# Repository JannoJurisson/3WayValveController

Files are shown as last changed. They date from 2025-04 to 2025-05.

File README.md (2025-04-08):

# 3WayValveController
Atmega328 based 3-way valve controller using a MG995 servo motor

A standalone controller using a Dallas DS18B20 sensor as input and MG995 servo motor as output that moves 3-way valve. Two end switches help to position the valve.

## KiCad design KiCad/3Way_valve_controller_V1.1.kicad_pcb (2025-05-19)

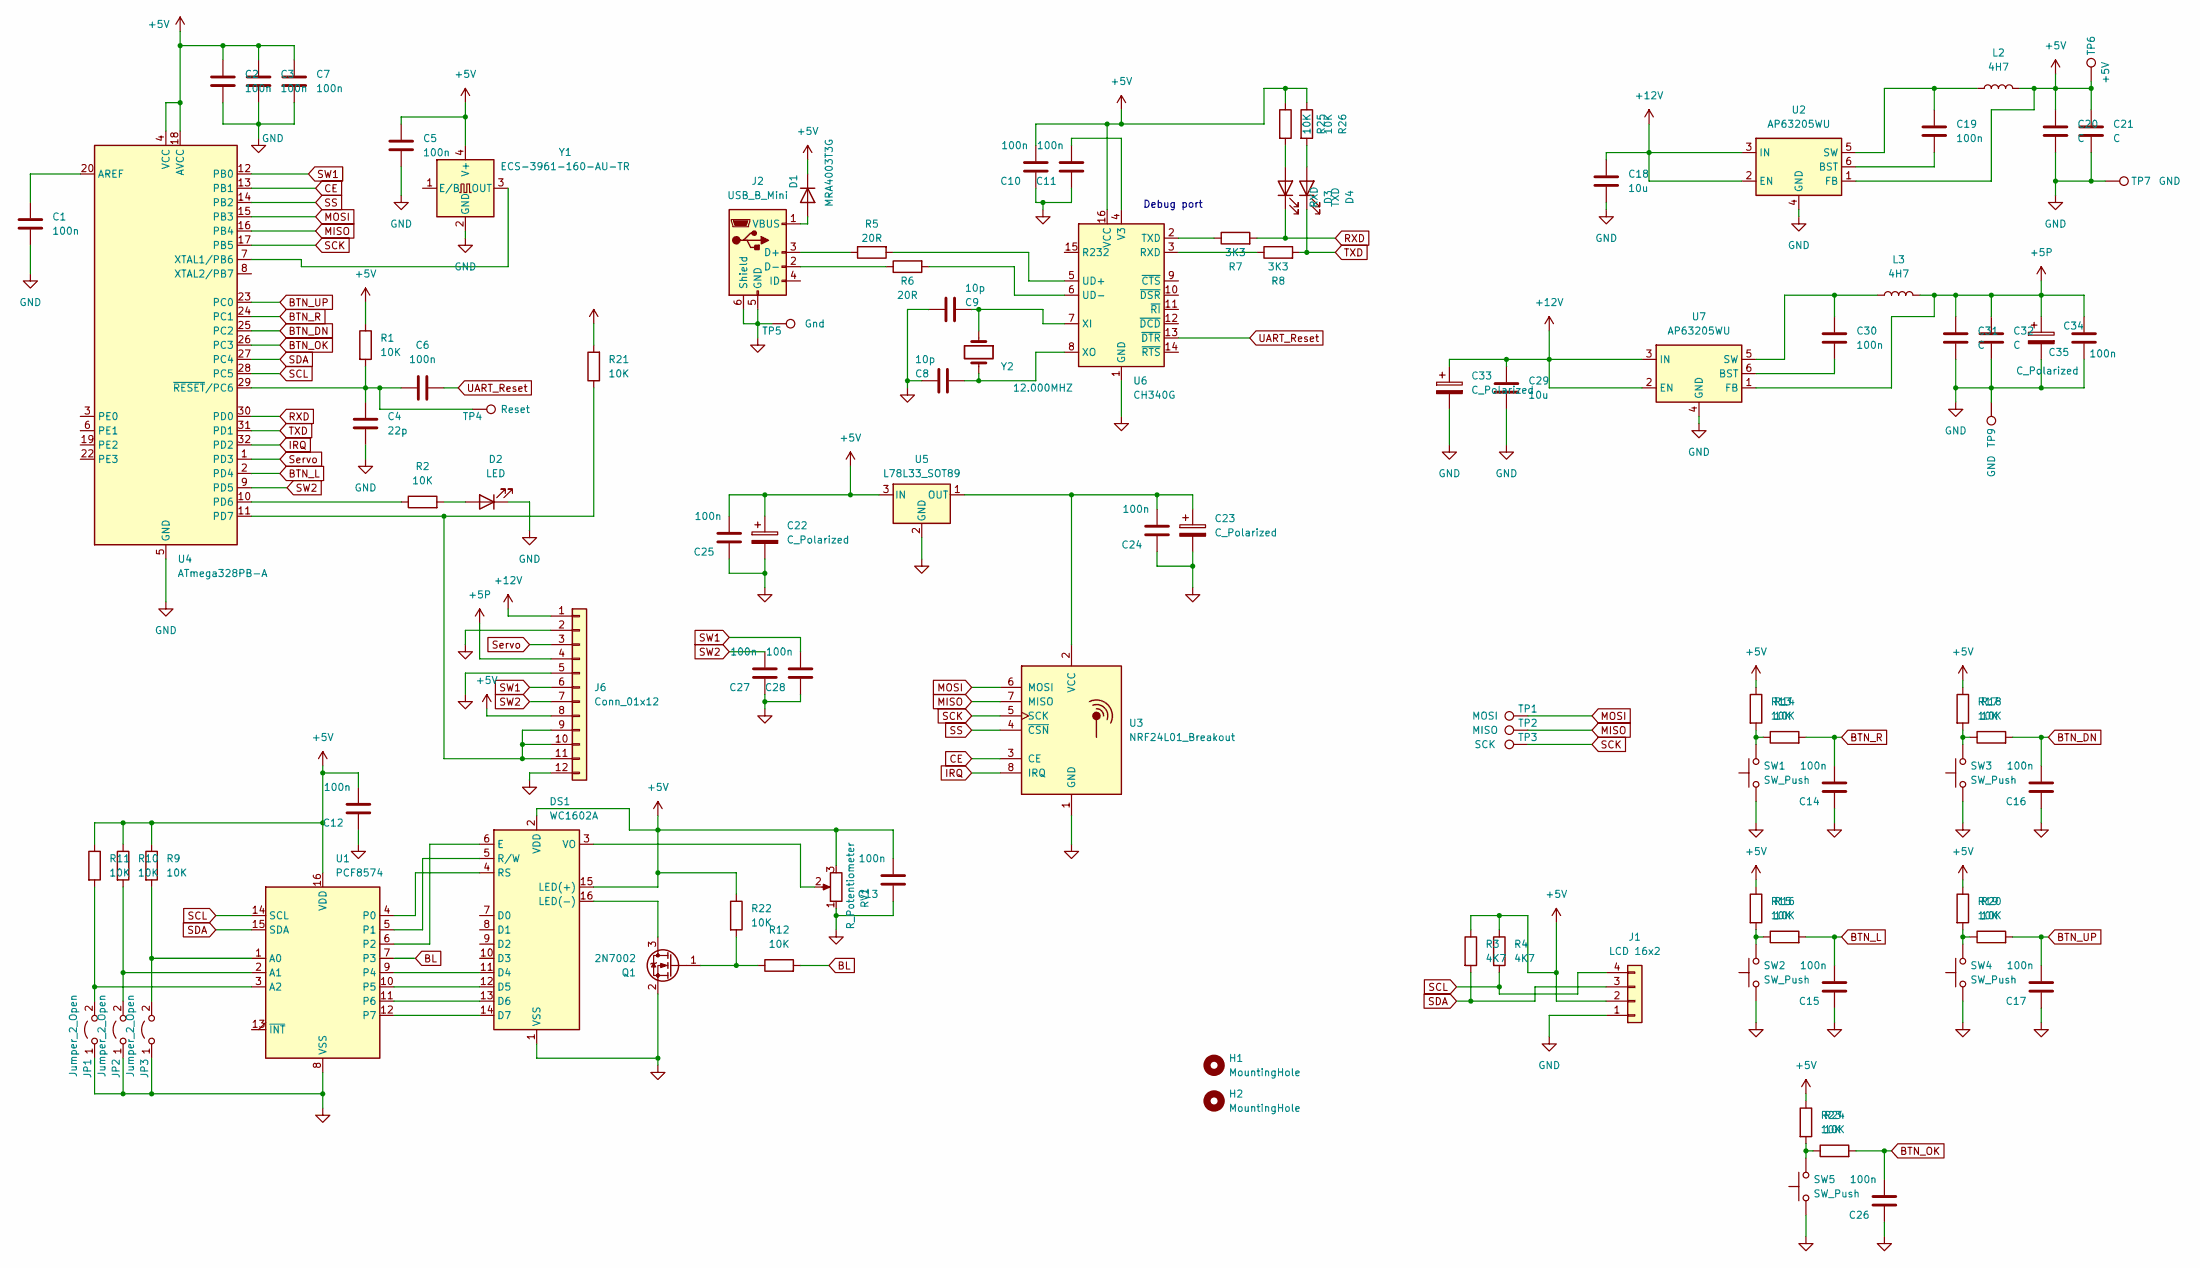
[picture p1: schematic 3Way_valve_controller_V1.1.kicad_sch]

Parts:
C1, C2, C3, C5, C6, C7, C14, C15, C16, C17, C19, C26, C30: 100n; C_0603_1608Metric
C4: 22p; C_0603_1608Metric
C8, C9: 10p; C_0603_1608Metric_Pad1.08x0.95mm_HandSolder
C10, C11, C12, C13, C24, C25, C27, C28, C35: 100n; C_0603_1608Metric_Pad1.08x0.95mm_HandSolder
C18, C29: 10u; C_1206_3216Metric
C20, C21, C31, C32: C; C_1206_3216Metric
C22, C23, C33, C34: C_Polarized; CP_Elec_10x10
D1: MRA4003T3G; D_SMA
D2: LED; LED_1206_3216Metric
D3: RXD; LED_1206_3216Metric
D4: TXD; LED_1206_3216Metric
DS1: WC1602A
H1, H2: MountingHole; MountingHole_3.2mm_M3
J1: LCD 16x2; PinHeader_1x04_P2.54mm_Vertical
J2: USB_B_Mini; JLCPCB_C404968_Micro_USB
J6: Conn_01x12; PhoenixContact_MCV_1,5_12-GF-3.5_1x12_P3.50mm_Vertical_Thre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
JP1, JP2, JP3: Jumper_2_Open; SolderJumper-2_P1.3mm_Open_Pad1.0x1.5mm
L2, L3: 4H7; L_Bourns_SRP7028A_7.3x6.6mm
Q1: 2N7002; SOT-23
R1, R2, R9, R10, R11, R12, R13, R14, R15, R16, R17, R18, R19, R20, R21, R22, R23, R24, R25, R26: 10K; R_0603_1608Metric
R3, R4: 4K7; R_0603_1608Metric
R5, R6: 20R; R_0603_1608Metric_Pad0.98x0.95mm_HandSolder
R7, R8: 3K3; R_0603_1608Metric_Pad0.98x0.95mm_HandSolder
RV1: R_Potentiometer; Potentiometer_Vishay_T73YP_Vertical
SW1, SW2, SW3, SW4, SW5: SW_Push; SW_PUSH_6mm
TP1: MOSI; TestPoint_Pad_D1.5mm
TP2: MISO; TestPoint_Pad_D1.5mm
TP3: SCK; TestPoint_Pad_D1.5mm
TP4: Reset; TestPoint_Pad_D1.5mm
TP5: Gnd; TestPoint_Pad_D1.5mm
TP6: +5V; TestPoint_Pad_D1.5mm
TP7, TP9: GND; TestPoint_Pad_D1.5mm
U1: PCF8574; SOIC-16W_7.5x10.3mm_P1.27mm
U2, U7: AP63205WU; TSOT-23-6
U3: NRF24L01_Breakout; nRF24L01_Breakout
U4: ATmega328PB-A; TQFP-32_7x7mm_P0.8mm
U5: L78L33_SOT89; SOT-89-3
U6: CH340G; SOIC-16_3.9x9.9mm_P1.27mm
Y1: ECS-3961-160-AU-TR; Oscillator_SMD_EuroQuartz_XO53-4Pin_5.0x3.2mm
Y2: 12.000MHZ; Crystal_SMD_5032-2Pin_5.0x3.2mm

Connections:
+5P: C31.1, C32.1, C34.1, C35.2, J6.4, L3.2, U7.1 (FB)
+5V: C2.2, C3.2, C5.2, C7.2, C10.2, C12.2, C13.2, C20.1, C21.1, C22.1, C25.2, D1.1 (K), DS1.2 (VDD), DS1.15 (LED(+)), J1.2, J6.8, L2.2, R1.1, R3.1, R4.1, R9.1, R10.1, R11.1, R13.1, R15.1, R17.1, R19.1, R21.2, R22.1, R23.1, R25.1, R26.1, RV1.3, TP6.1, U1.16 (VDD), U2.1 (FB), U4.4 (VCC), U4.18 (AVCC), U5.3 (IN), U6.16 (VCC), Y1.4 (V+)
+12V: C18.1, C29.1, C33.1, J6.1, U2.2 (EN), U2.3 (IN), U7.2 (EN), U7.3 (IN)
BL: R12.2, U1.7 (P3)
BTN_DN: C16.2, R18.2, U4.25 (PC2)
BTN_L: C15.2, R16.2, U4.2 (PD4)
BTN_OK: C26.2, R24.2, U4.26 (PC3)
BTN_R: C14.2, R14.2, U4.24 (PC1)
BTN_UP: C17.2, R20.2, U4.23 (PC0)
CE: U3.3 (CE), U4.13 (PB1)
GND: C1.1, C2.1, C3.1, C4.1, C5.1, C7.1, C8.2, C9.2, C10.1, C11.1, C12.1, C13.1, C14.1, C15.1, C16.1, C17.1, C18.2, C20.2, C21.2, C22.2, C23.2, C24.1, C25.1, C26.1, C27.1, C28.1, C29.2, C31.2, C32.2, C33.2, C34.2, C35.1, D2.1 (K), DS1.1 (VSS), J1.1, J2.5 (GND), J2.6 (Shield), J6.2, J6.5, J6.12, JP1.1 (A), JP2.1 (A), JP3.1 (A), Q1.2 (S), RV1.1, SW1.1, SW2.1, SW3.1, SW4.1, SW5.1, TP5.1, TP7.1, TP9.1, U1.8 (VSS), U2.4 (GND), U3.1 (GND), U4.5 (GND), U4.21 (GND), U5.2 (GND), U6.1 (GND), U7.4 (GND), Y1.2 (GND)
IRQ: U3.8 (IRQ), U4.32 (PD2)
MISO: TP2.1, U3.7 (MISO), U4.16 (PB4)
MOSI: TP1.1, U3.6 (MOSI), U4.15 (PB3)
unnamed: D1.2 (A), J2.1 (VBUS)
unnamed: D2.2 (A), R2.2
unnamed: D3.2 (A), R25.2
unnamed: D4.2 (A), R26.2
unnamed: DS1.11 (D4), U1.9 (P4)
unnamed: DS1.12 (D5), U1.10 (P5)
unnamed: DS1.13 (D6), U1.11 (P6)
unnamed: DS1.14 (D7), U1.12 (P7)
unnamed: DS1.6 (E), U1.6 (P2)
unnamed: DS1.16 (LED(-)), Q1.3 (D)
unnamed: DS1.4 (RS), U1.4 (P0)
unnamed: DS1.5 (R/W), U1.5 (P1)
unnamed: DS1.3 (VO), RV1.2
unnamed: J2.3 (D+), R5.1
unnamed: J2.2 (D-), R6.1
unnamed: J6.9, J6.10, J6.11, R21.1, U4.11 (PD7)
unnamed: JP1.2 (B), R11.2, U1.3 (A2)
unnamed: JP2.2 (B), R10.2, U1.2 (A1)
unnamed: JP3.2 (B), R9.2, U1.1 (A0)
unnamed: Q1.1 (G), R12.1, R22.2
unnamed: R13.2, R14.1, SW1.2
unnamed: R15.2, R16.1, SW2.2
unnamed: R17.2, R18.1, SW3.2
unnamed: R19.2, R20.1, SW4.2
unnamed: R23.2, R24.1, SW5.2
unnamed: C19.2, U2.6 (BST)
unnamed: C19.1, L2.1, U2.5 (SW)
unnamed: C23.1, C24.2, U3.2 (VCC), U5.1 (OUT)
unnamed: C1.2, U4.20 (AREF)
unnamed: R2.1, U4.10 (PD6)
unnamed: U4.7 (XTAL1/PB6), Y1.3 (OUT)
unnamed: C4.2, C6.1, R1.2, TP4.1, U4.29 (~RESET/PC6)
unnamed: R8.1, U6.3 (RXD)
unnamed: R7.1, U6.2 (TXD)
unnamed: R5.2, U6.5 (UD+)
unnamed: R6.2, U6.6 (UD-)
unnamed: C11.2, U6.4 (V3)
unnamed: C9.1, U6.7 (XI), Y2.1
unnamed: C8.1, U6.8 (XO), Y2.2
unnamed: C30.2, U7.6 (BST)
unnamed: C30.1, L3.1, U7.5 (SW)
RXD: D3.1 (K), R7.2, U4.30 (PD0)
SCK: TP3.1, U3.5 (SCK), U4.17 (PB5)
SCL: J1.4, R4.2, U1.14 (SCL), U4.28 (PC5)
SDA: J1.3, R3.2, U1.15 (SDA), U4.27 (PC4)
SS: U3.4 (~CSN), U4.14 (PB2)
SW1: C28.2, J6.6, U4.12 (PB0)
SW2: C27.2, J6.7, U4.9 (PD5)
Servo: J6.3, U4.1 (PD3)
TXD: D4.1 (K), R8.2, U4.31 (PD1)
UART_Reset: C6.2, U6.13 (~DTR)

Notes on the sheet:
Debug port

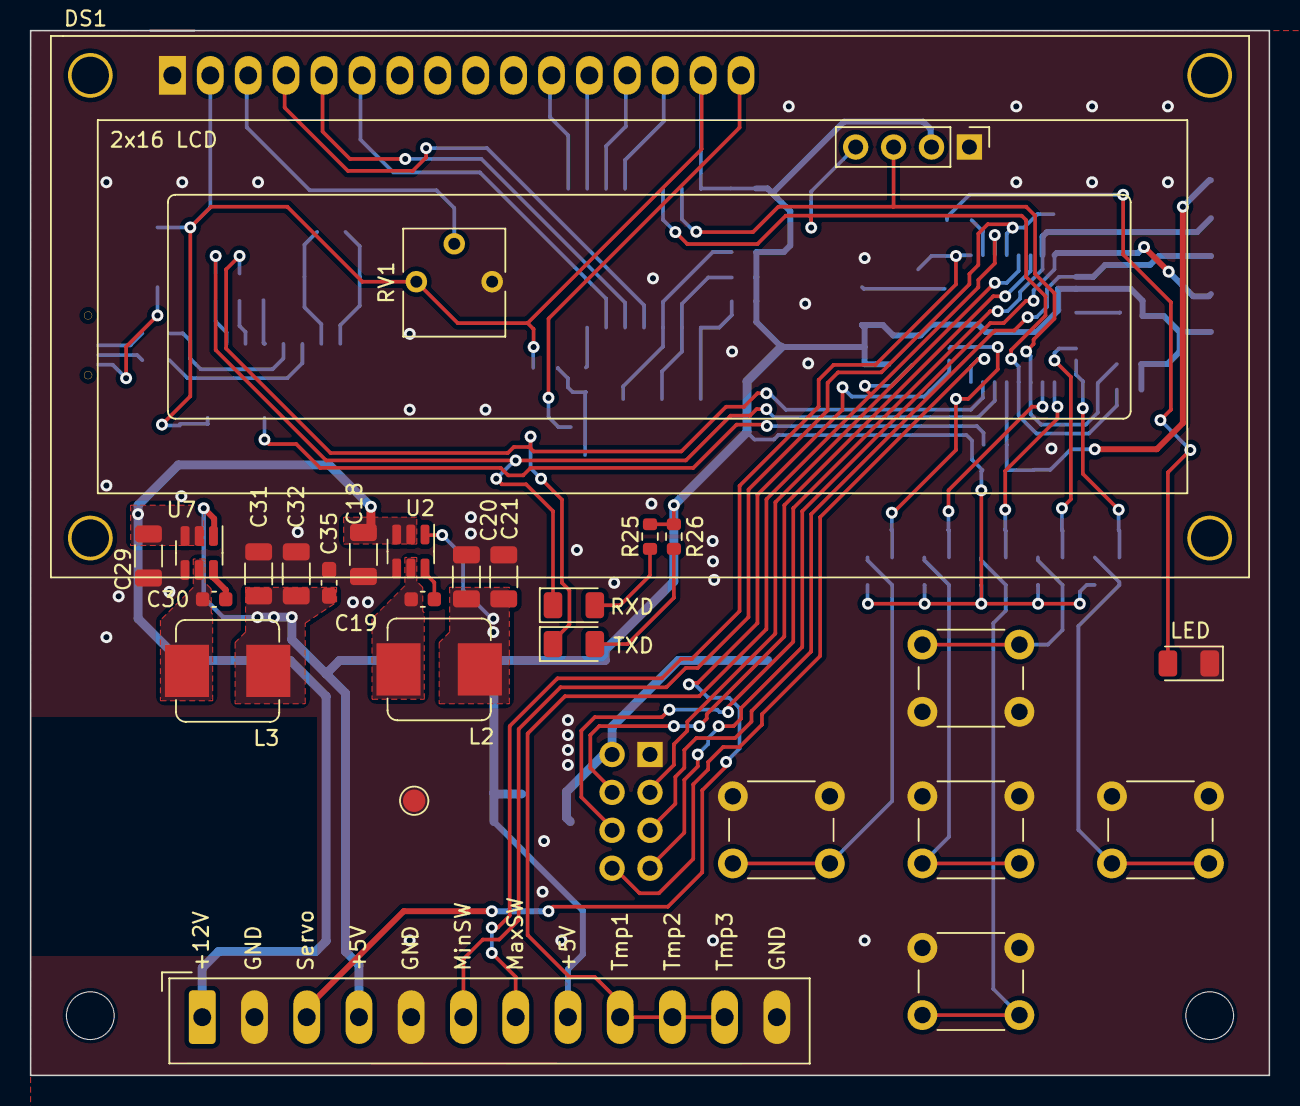
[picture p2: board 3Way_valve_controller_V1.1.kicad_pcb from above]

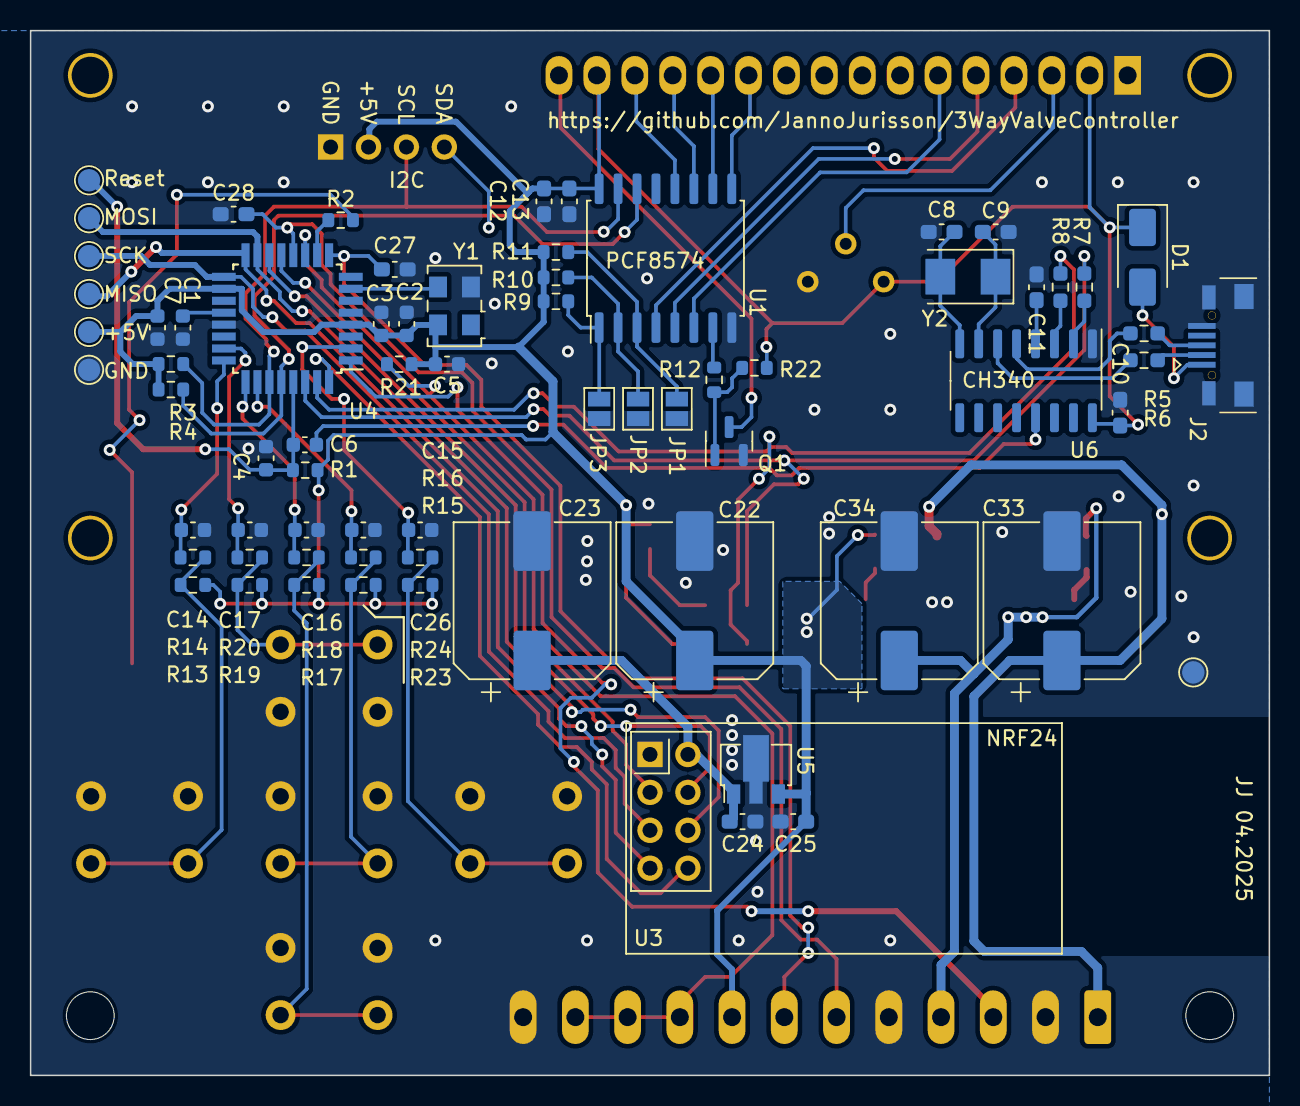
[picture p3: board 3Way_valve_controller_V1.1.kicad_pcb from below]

Board: 2 copper layers, 83.0 x 70.0 mm, 100 parts (70 on the bottom side), 65 nets.

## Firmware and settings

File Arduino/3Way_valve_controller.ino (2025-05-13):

#include <Wire.h>
#include <Servo.h>
#include <PID_v1.h>
#include <LiquidCrystal_I2C.h>
#include <EEPROM.h>
#include <OneWire.h>
#include <DallasTemperature.h>
#include <SPI.h>
#include "printf.h"
#include "RF24.h"

#define TEMPERATURE_PRECISION 9

#define CE_PIN 9
#define CSN_PIN 10
// RF24 configuration
RF24 radio(CE_PIN, CSN_PIN);
uint8_t address[][6] = { "1Node", "2Node" };
bool radioNumber = 0;  // 0 uses address[0] to transmit, 1 uses address[1] to transmit
bool role = true;  // true = TX role, false = RX role
float payload = 0.0;

// Structure to send two temperatures
struct TempData {
  float temp1;
  float temp2;
  float temp3;
};
  TempData data;

#define ONE_WIRE_BUS 7  // Dallas temp sensor data pin
#define SERVO_PIN 3
#define MIN_LIMIT_SWITCH 8  // Active LOW (0 when pressed)
#define MAX_LIMIT_SWITCH 5
#define LED_STATUS 6


#define BTN_UP A0
#define BTN_DOWN A4
#define BTN_LEFT 4
#define BTN_RIGHT A1
#define BTN_OK A3

Servo valveServo;
OneWire oneWire(ONE_WIRE_BUS);
DallasTemperature sensors(&oneWire);
// arrays to hold device addresses
DeviceAddress soilThermometer, valveThermometer, airThermometer;

double setpoint, Kp, Ki, Kd, inputTemp, outputServo, setpointTemp;
float currentTemp = 0.0; 
PID myPID(&inputTemp, &outputServo, &setpointTemp, Kp, Ki, Kd, DIRECT);
LiquidCrystal_I2C lcd(0x27, 16, 2);

int menuIndex = 0;  // 0=Set Temp, 1=Kp, 2=Ki, 3=Kd
const char* menuItems[] = { "Set Temp", "Kp Value", "Ki Value", "Kd Value" };

unsigned long lastButtonPress = 0;
bool menuActive = true;

float lastSetpoint = -100.0;
float lastCurrentTemp = -100.0;
unsigned long lastLcdUpdate = 0;
const unsigned long lcdUpdateInterval = 1000;  // Update LCD every 1 second

unsigned long lastButtonPressTime = 0;
const unsigned long buttonDebounceTime = 300;  // 300ms debounce delay
const unsigned long menuTimeout = 5000;        // 10s timeout
int lastServoPos = -1;                         // Store the last servo position

float lastKp = -100.0;
float lastKi = -100.0;
float lastKd = -100.0;

int minServoAngle = 0;
int maxServoAngle = 90;
unsigned long lastServoUpdate = 0;
const unsigned long servoUpdateInterval = 5000;  // 5 seconds
bool servoAttached = false;


unsigned long currentMillis;
unsigned long prevMillis;
int LED_delay = 1000;

void setup() {
  Serial.begin(9600);
  Serial.println("start");
  sensors.begin();
  // locate devices on the bus
  Serial.print("Locating devices...");
  Serial.print("Found ");
  Serial.print(sensors.getDeviceCount(), DEC);
  Serial.println(" devices.");

  if (!sensors.getAddress(soilThermometer, 0)) Serial.println("Unable to find address for Device 0");
  if (!sensors.getAddress(valveThermometer, 1)) Serial.println("Unable to find address for Device 1");
  if (!sensors.getAddress(airThermometer, 2)) Serial.println("Unable to find address for Device 2");

  Serial.print("Device 0 Address: ");
  printAddress(soilThermometer);
  Serial.println();

  Serial.print("Device 1 Address: ");
  printAddress(valveThermometer);
  Serial.println();

  Serial.print("Device 2 Address: ");
  printAddress(airThermometer);
  Serial.println();


  sensors.setResolution(soilThermometer, TEMPERATURE_PRECISION);
  sensors.setResolution(valveThermometer, TEMPERATURE_PRECISION);
    sensors.setResolution(airThermometer, TEMPERATURE_PRECISION);


  pinMode(MIN_LIMIT_SWITCH, INPUT_PULLUP);
  pinMode(MAX_LIMIT_SWITCH, INPUT_PULLUP);
  pinMode(BTN_UP, INPUT_PULLUP);
  pinMode(BTN_DOWN, INPUT_PULLUP);
  pinMode(BTN_LEFT, INPUT_PULLUP);
  pinMode(BTN_RIGHT, INPUT_PULLUP);
  pinMode(LED_STATUS, OUTPUT);

  EEPROM.get(0, setpoint);
  EEPROM.get(4, Kp);
  EEPROM.get(8, Ki);
  EEPROM.get(12, Kd);

  if (isnan(setpoint)) setpoint = 40.0;
  if (isnan(Kp)) Kp = 3.0;
  if (isnan(Ki)) Ki = 0.5;
  if (isnan(Kd)) Kd = 1.0;

  if (!radio.begin()) {
    Serial.println(F("radio hardware is not responding!!"));
  }
 radio.setPALevel(RF24_PA_MAX);  // RF24_PA_MAX is default.
  radio.setPayloadSize(sizeof(data));  // float datatype occupies 4 bytes
  radio.stopListening(address[radioNumber]);  // put radio in TX mode
  radio.openReadingPipe(1, address[!radioNumber]);  // using pipe 1
  if (!role) {
    radio.startListening();  // put radio in RX mode
  }


  valveServo.attach(SERVO_PIN);

  lcd.init();
  lcd.backlight();
  showMainScreen();

  //int lastServoPos = loadLastServoPosition();
  // Move toward max limit until the max switch is pressed
  for (int angle = 90; angle <= 180; angle++) {
    valveServo.write(angle);
    Serial.println(angle);
    delay(200);
    if (digitalRead(MAX_LIMIT_SWITCH) == HIGH) {
      maxServoAngle = angle;
      break;  // Max limit reached
    }
  }


  // Move back toward min limit until the min switch is pressed
  for (int angle = maxServoAngle; angle >= 0; angle--) {
    valveServo.write(angle);
    delay(200);
    Serial.println(angle);
    if (digitalRead(MIN_LIMIT_SWITCH) == HIGH) {
      minServoAngle = angle;
      break;  // Min limit reached
    }
  }

  valveServo.detach();
  servoAttached = false;

  Serial.print("Minimum servo angle = ");
  Serial.println(minServoAngle);
  Serial.print("Maximum servo angle = ");
  Serial.println(maxServoAngle);

  setpointTemp = setpoint;
  myPID.SetTunings(Kp, Ki, Kd);
  myPID.SetMode(AUTOMATIC);
  myPID.SetOutputLimits(minServoAngle, maxServoAngle);


}

void loop() {

  if (millis() - prevMillis > LED_delay) {
    digitalWrite(LED_STATUS, !digitalRead(LED_STATUS));

    prevMillis = millis();
  }


  unsigned long now = millis();

  if (now - lastServoUpdate >= servoUpdateInterval) {

    lastServoUpdate = now;
    currentTemp = readTemperatureDallas();

    //nrf24
  
    data.temp1 = sensors.getTempCByIndex(0);
    data.temp2 = sensors.getTempCByIndex(1);
    data.temp3 = sensors.getTempCByIndex(2);

    Serial.print("Sending data...");
  if (role) {
    // This device is a TX node
payload = data.temp2;
    unsigned long start_timer = micros();                // start the timer
    bool report = radio.write(&data, sizeof(data));  // transmit & save the report
    unsigned long end_timer = micros();                  // end the timer

    if (report) {
      Serial.print(F("Transmission successful! "));  // payload was delivered
      Serial.print(F("Time to transmit = "));
      Serial.print(end_timer - start_timer);  // print the timer result
      Serial.print(F(" us. Sent: "));
      Serial.println(payload);  // print payload sent
      payload += 0.01;          // increment float payload
      LED_delay = 1500;
    } else {
LED_delay = 300;
      Serial.println(F("Transmission failed or timed out"));  // payload was not delivered
    }

    // to make this example readable in the serial monitor
    

  } else {
    // This device is a RX node

    uint8_t pipe;
    if (radio.available(&pipe)) {              // is there a payload? get the pipe number that received it
      uint8_t bytes = radio.getPayloadSize();  // get the size of the payload
      radio.read(&payload, bytes);             // fetch payload from FIFO
      Serial.print(F("Received "));
      Serial.print(bytes);  // print the size of the payload
      Serial.print(F(" bytes on pipe "));
      Serial.print(pipe);  // print the pipe number
      Serial.print(F(": "));
      Serial.println(payload);  // print the payload's value
    }
  }  // role


    if (currentTemp > -55 && currentTemp < 125) {  // Valid DS18B20 range
      inputTemp = currentTemp;
      setpointTemp = setpoint;
      myPID.Compute();

      int newServoPos = constrain((int)outputServo, minServoAngle, maxServoAngle);

      if (isWithinLimits(newServoPos)) {
        if (abs(newServoPos - lastServoPos) > 1) {

          if (!servoAttached) {
            valveServo.attach(SERVO_PIN);
            servoAttached = true;
          }

          valveServo.write(newServoPos);
          lastServoPos = newServoPos;

          // Detach after short delay to let servo move
          delay(300);
          valveServo.detach();
          servoAttached = false;
        }
      }

      Serial.print("Temp: ");
      Serial.print(currentTemp);
      Serial.print(" °C | Servo: ");
      Serial.println(newServoPos);
    }
  }

  handleMenu();

  if (menuActive) {
    showMenu();

  } else {
    showMainScreen();
  }
}


void handleMenu() {
  unsigned long currentMillis = millis();

  // Check if menu was inactive and a button is pressed
  if (!menuActive) {
    if (digitalRead(BTN_LEFT) == LOW || digitalRead(BTN_RIGHT) == LOW || digitalRead(BTN_UP) == LOW || digitalRead(BTN_DOWN) == LOW) {
      resetTimeout();  // Reactivate menu
      showMenu();
    }
    return;  // Skip the rest of the function until menu is active
  }

  // Timeout: return to main screen after 10 sec
  if (currentMillis - lastButtonPressTime > menuTimeout) {
    menuActive = false;
    showMainScreen();
    return;
  }

  if (currentMillis - lastButtonPressTime < buttonDebounceTime) {
    return;  // Ignore fast button presses
  }

  if (digitalRead(BTN_LEFT) == LOW) {
    menuIndex = (menuIndex + 3) % 4;
    resetTimeout();
  }
  if (digitalRead(BTN_RIGHT) == LOW) {
    menuIndex = (menuIndex + 1) % 4;
    resetTimeout();
  }
  if (digitalRead(BTN_UP) == LOW) {
    adjustValue(menuIndex, 1);
    resetTimeout();
  }
  if (digitalRead(BTN_DOWN) == LOW) {
    adjustValue(menuIndex, -1);
    resetTimeout();
  }

  showMenu();
}

void showMenu() {
  static int lastMenuIndex = -1;      // Track menu index changes
  static bool lastMenuState = false;  // Track menu state changes

  // Only update LCD if menu index or state changed
  if (lastMenuIndex != menuIndex || lastMenuState != menuActive) {
    lcd.clear();  // Clear the screen to remove old data
    lcd.setCursor(0, 0);
    lcd.print(menuItems[menuIndex]);
    lastMenuIndex = menuIndex;   // Update the last menu index
    lastMenuState = menuActive;  // Update the last menu state
  }

  // Update the numerical value only when it changes, or show it on first entry
  lcd.setCursor(0, 1);  // Move to second row
  switch (menuIndex) {
    case 0:  // Setpoint menu
      if (setpoint != lastSetpoint || lastSetpoint == -100.0) {
        lcd.print("Value: ");
        lcd.print(setpoint, 1);   // Update setpoint if changed
        lastSetpoint = setpoint;  // Save the current value
      }
      break;
    case 1:  // Kp menu
      if (Kp != lastKp || lastKp == -100.0) {
        lcd.print("Value: ");
        lcd.print(Kp, 2);  // Update Kp if changed
        lastKp = Kp;       // Save the current value
      }
      break;
    case 2:  // Ki menu
      if (Ki != lastKi || lastKi == -100.0) {
        lcd.print("Value: ");
        lcd.print(Ki, 2);  // Update Ki if changed
        lastKi = Ki;       // Save the current value
      }
      break;
    case 3:  // Kd menu
      if (Kd != lastKd || lastKd == -100.0) {
        lcd.print("Value: ");
        lcd.print(Kd, 2);  // Update Kd if changed
        lastKd = Kd;       // Save the current value
      }
      break;
  }
}

void resetTimeout() {
  lastButtonPressTime = millis();
  menuActive = true;
}


void showMainScreen() {
  unsigned long currentMillis = millis();

  // Update LCD only if values have changed OR every lcdUpdateInterval
  if ((setpoint != lastSetpoint || currentTemp != lastCurrentTemp) || (currentMillis - lastLcdUpdate >= lcdUpdateInterval)) {

    lastLcdUpdate = currentMillis;
    lastSetpoint = setpoint;
    lastCurrentTemp = currentTemp;

    lcd.clear();
    lcd.setCursor(0, 1);
    lcd.print("S: ");
    lcd.print(data.temp1, 1);
    lcd.print("C");

    lcd.setCursor(9, 1);
    lcd.print("V: ");
    lcd.print(currentTemp);
    lcd.print("C");

    lcd.setCursor(0, 0);
    lcd.print("A: ");
    lcd.print(data.temp3, 1);
    lcd.print("C");

    unsigned long ms = millis();
    unsigned long totalSeconds = ms / 1000;

    unsigned int seconds = totalSeconds % 60;
    unsigned int minutes = (totalSeconds / 60) % 999999;
    unsigned int hours = (totalSeconds / 3600) % 24;
    unsigned int days = totalSeconds / 86400;
   // lcd.print("d");
   // lcd.setCursor(1, 0);
   // lcd.print(days);
    //lcd.setCursor(4, 0);
   // lcd.print("h:");
   // lcd.setCursor(6, 0);
   // lcd.print(hours);
    lcd.setCursor(9, 0);
    lcd.print("m:");
    lcd.setCursor(11, 0);
    lcd.print(minutes);
   // lcd.setCursor(12, 0);
    //lcd.print("s:");
    //lcd.setCursor(14, 0);
    //lcd.print(seconds);
  }
}


void adjustValue(int index, int step) {
  switch (index) {
    case 0:
      setpoint += step * 0.5;
      EEPROM.put(0, setpoint);
      break;
    case 1:
      Kp += step * 0.1;
      EEPROM.put(4, Kp);
      myPID.SetTunings(Kp, Ki, Kd);
      break;
    case 2:
      Ki += step * 0.1;
      EEPROM.put(8, Ki);
      myPID.SetTunings(Kp, Ki, Kd);
      break;
    case 3:
      Kd += step * 0.1;
      EEPROM.put(12, Kd);
      myPID.SetTunings(Kp, Ki, Kd);
      break;
  }
}

float readTemperatureDallas() {
  sensors.requestTemperatures();             // Send the command to get temperatures
  float tempC = sensors.getTempCByIndex(1);  // sensor with index should be valve sensor

  return tempC;
}

void saveServoPosition(int position) {
  EEPROM.put(16, position);  // Store at address 16 (just after Kd at 12)
}

int loadLastServoPosition() {
  int pos;
  EEPROM.get(16, pos);
  if (pos < 0 || pos > 180) {
    pos = 90;  // Default safe middle position
  }
  return pos;
}


//  Prevents servo from exceeding 90° range using limit switches
bool isWithinLimits(int position) {
  if (digitalRead(MIN_LIMIT_SWITCH) == HIGH && position <= minServoAngle) return false;
  if (digitalRead(MAX_LIMIT_SWITCH) == HIGH && position >= maxServoAngle) return false;
  return true;
}

// function to print a device address
void printAddress(DeviceAddress deviceAddress) {
  for (uint8_t i = 0; i < 8; i++) {
    // zero pad the address if necessary
    if (deviceAddress[i] < 16) Serial.print("0");
    Serial.print(deviceAddress[i], HEX);
  }
}

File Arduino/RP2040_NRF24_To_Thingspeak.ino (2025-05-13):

#include <SPI.h>
#include <RF24.h>
#include <WiFi.h>
#include <WiFiClient.h>


#define LED_STATUS 25

/* Wi-Fi info */
char ssid[] = "Telia-7DCD82";  // your network SSID (name)
char pass[] = "PipijaFelix";   // your network password
WiFiMulti multi;


int status = WL_IDLE_STATUS;  // the Wifi radio's status

char server[] = "api.thingspeak.com";  // server address
String apiKey = "5063D0Z14L0G4Q9U";    // apki key

unsigned long myChannelNumber = 377529;
const char* myWriteAPIKey = "5063D0Z14L0G4Q9U";

// Thingspeak

unsigned long lastThingSpeakUpdate = 0;  // last time you connected to the server, in milliseconds
unsigned long lastConnectionTime = 0;    // last time you connected to the server, in milliseconds
unsigned long NRF24_connect_interval = 0;
WiFiClient client;

#define CE_PIN 5
#define CSN_PIN 8

// RF24 configuration
RF24 radio(CE_PIN, CSN_PIN);


uint8_t address[][6] = { "1Node", "2Node" };
bool radioNumber = 1;  // 0 uses address[0] to transmit, 1 uses address[1] to transmit
bool role = false;     // true = TX role, false = RX role
float payload = 0.0;


struct TempData {
  float temp1;
  float temp2;
  float temp3;
};

TempData data;
unsigned long prevMillis = 0;
int LED_delay = 1000;

void setup() {
//  Serial.begin(9600);
  //while (!Serial)
    ;  // <-- Add this line!

pinMode(LED_BUILTIN, OUTPUT);

  SPI.setRX(4);
  SPI.setTX(7);
  SPI.setSCK(6);
  SPI.setCS(5);

  // We start by connecting to a WiFi network
  
  Serial.println();
  Serial.println();
  Serial.print("Connecting to ");
  Serial.println(ssid);

  multi.addAP(ssid, pass);

  if (multi.run() != WL_CONNECTED) {
    Serial.println("Unable to connect to network");
    LED_delay = 300;
    //rp2040.reboot();
  }
  else{
    LED_delay = 2000;
  }

  Serial.println("");
  Serial.println("WiFi connected");
  Serial.println("IP address: ");
  Serial.println(WiFi.localIP());


  if (!radio.begin()) {
    Serial.println(F("radio hardware is not responding!!"));
  }
  radio.setPALevel(RF24_PA_MAX);                    // RF24_PA_MAX is default.
  radio.setPayloadSize(sizeof(data));            // float datatype occupies 4 bytes
  radio.stopListening(address[radioNumber]);        // put radio in TX mode
  radio.openReadingPipe(1, address[!radioNumber]);  // using pipe 1
  if (!role) {
    radio.startListening();  // put radio in RX mode
  }
}

void loop() {

   if (millis() - prevMillis > LED_delay) {
    digitalWrite(LED_BUILTIN, !digitalRead(LED_BUILTIN));

    prevMillis = millis();
  }

   if (millis() - NRF24_connect_interval > 30000) {

  if (multi.run() != WL_CONNECTED) {
    LED_delay = 300;
  }
  else{
    LED_delay = 2000;
  }

      NRF24_connect_interval = millis();
   }
  if (role) {
    // This device is a TX node

    unsigned long start_timer = micros();                // start the timer
    bool report = radio.write(&payload, sizeof(float));  // transmit & save the report
    unsigned long end_timer = micros();                  // end the timer

    if (report) {
      Serial.print(F("Transmission successful! "));  // payload was delivered
      Serial.print(F("Time to transmit = "));
      Serial.print(end_timer - start_timer);  // print the timer result
      Serial.print(F(" us. Sent: "));
      Serial.println(payload);  // print payload sent
      payload += 0.01;          // increment float payload
    } else {
      Serial.println(F("Transmission failed or timed out"));  // payload was not delivered
    }

    // to make this example readable in the serial monitor
   delay(1000); 

  } else {
    // This device is a RX node

    uint8_t pipe;
    if (radio.available(&pipe)) {              // is there a payload? get the pipe number that received it
      uint8_t bytes = radio.getPayloadSize();  // get the size of the payload
      radio.read(&data, bytes);                // fetch payload from FIFO
      Serial.print(F("Received "));
      Serial.print(bytes);  // print the size of the payload
      Serial.print(F(" bytes on pipe "));
      Serial.print(pipe);  // print the pipe number
      Serial.print(F(": "));
      Serial.print("Data1:");
      Serial.println(data.temp1);
      Serial.print("Data2:");
      Serial.println(data.temp2);
      Serial.print("Data3:");
      Serial.println(data.temp3);
    }
  }  // role


  // Log Temperature to ThingSpeak every 30 min
  if (millis() - lastThingSpeakUpdate >= 600000) { // 30 minutes600000

    SendThingSpeak();
    lastThingSpeakUpdate = millis();
  }

}


void SendThingSpeak() {


  if (multi.run() != WL_CONNECTED) {
    multi.addAP(ssid, pass);
    delay(5000);
  }
  printWifiStatus();
  // close any connection before send a new request
  // this will free the socket on the WiFi shield
  client.stop();

  // if there's a successful connection
  if (client.connect(server, 80)) {
    Serial.println("Connecting...");

    // send the Get request
    client.print(F("GET /update?api_key="));
    client.print(apiKey);
    client.print(F("&field3="));
    client.print(String(data.temp1));
    client.print(F("&field4="));
    client.print(String(data.temp2));
    client.print(F("&field5="));
    client.print(String(data.temp3));
    client.println();
    // note the time that the connection was made
    lastConnectionTime = millis();
   
  } else {
    // if you couldn't make a connection
   
    Serial.println("Connection failed");
  }
}


void printWifiStatus() {
  // print the SSID of the network you're attached to
  Serial.print("SSID: ");
  Serial.println(WiFi.SSID());

  // print your WiFi shield's IP address
  IPAddress ip = WiFi.localIP();
  Serial.print("IP Address: ");
  Serial.println(ip);

  // print the received signal strength
  long rssi = WiFi.RSSI();
  Serial.print("Signal strength (RSSI):");
  Serial.print(rssi);
  Serial.println(" dBm");
}

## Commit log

2025-05-19 Delete KiCad/3Way_valve_controller.kicad_pcb
    Old version
    [3Way_valve_controller.kicad_pcb]
2025-05-19 Delete KiCad/3Way_valve_controller.kicad_prl
    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
2025-05-19 Delete KiCad/3Way_valve_controller.kicad_pro
    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
2025-05-19 Delete KiCad/3Way_valve_controller.kicad_sch
    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
    [3Way_valve_controller.kicad_sch]
